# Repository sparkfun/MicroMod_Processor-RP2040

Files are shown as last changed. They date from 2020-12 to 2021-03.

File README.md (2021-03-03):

SparkFun MicroMod Processor RP2040
========================================

SparkFun MicroMod Processor RP2040 (https://www.sparkfun.com/products/17720)

[*SparkFun MicroMod Processor RP2040 (DEV-17720)*](https://www.sparkfun.com/products/17720)

The SparkFun MicroMod Pi RP2040 Processor Board is a low-cost, high-performance board with flexible digital interfaces featuring the Raspberry Pi Foundation's RP2040 microcontroller. With the MicroMod M.2 connector, connecting your MicroMod Pi RP2040 Processor Board is a breeze. Simply match up the key on your processor's beveled edge connector to the key on the M.2 connector and secure it with a screw (included with all Carrier Boards).

Repository Contents
-------------------

* **/Documentation** - Data sheets, additional product information
* **/Hardware** - Eagle design files (.brd, .sch)

Documentation
--------------

* **[Hookup Guide](https://learn.sparkfun.com/tutorials/1495)** - Basic hookup guide for the MicroMod Processor RP2040
* **[SparkFun Graphical Datasheets](https://github.com/sparkfun/Graphical_Datasheets)** - Graphical datasheets for various SparkFun products.

Product Versions
----------------

* [DEV-17720](https://www.sparkfun.com/products/17720) -  initial release

License Information
-------------------

This product is _**open source**_! 

Please review the LICENSE.md file for license information. 

If you have any questions or concerns on licensing, please contact technical support on our [SparkFun forums](https://forum.sparkfun.com/viewforum.php?f=152).

Distributed as-is; no warranty is given.

- Your friends at SparkFun.

_<COLLABORATION CREDIT>_

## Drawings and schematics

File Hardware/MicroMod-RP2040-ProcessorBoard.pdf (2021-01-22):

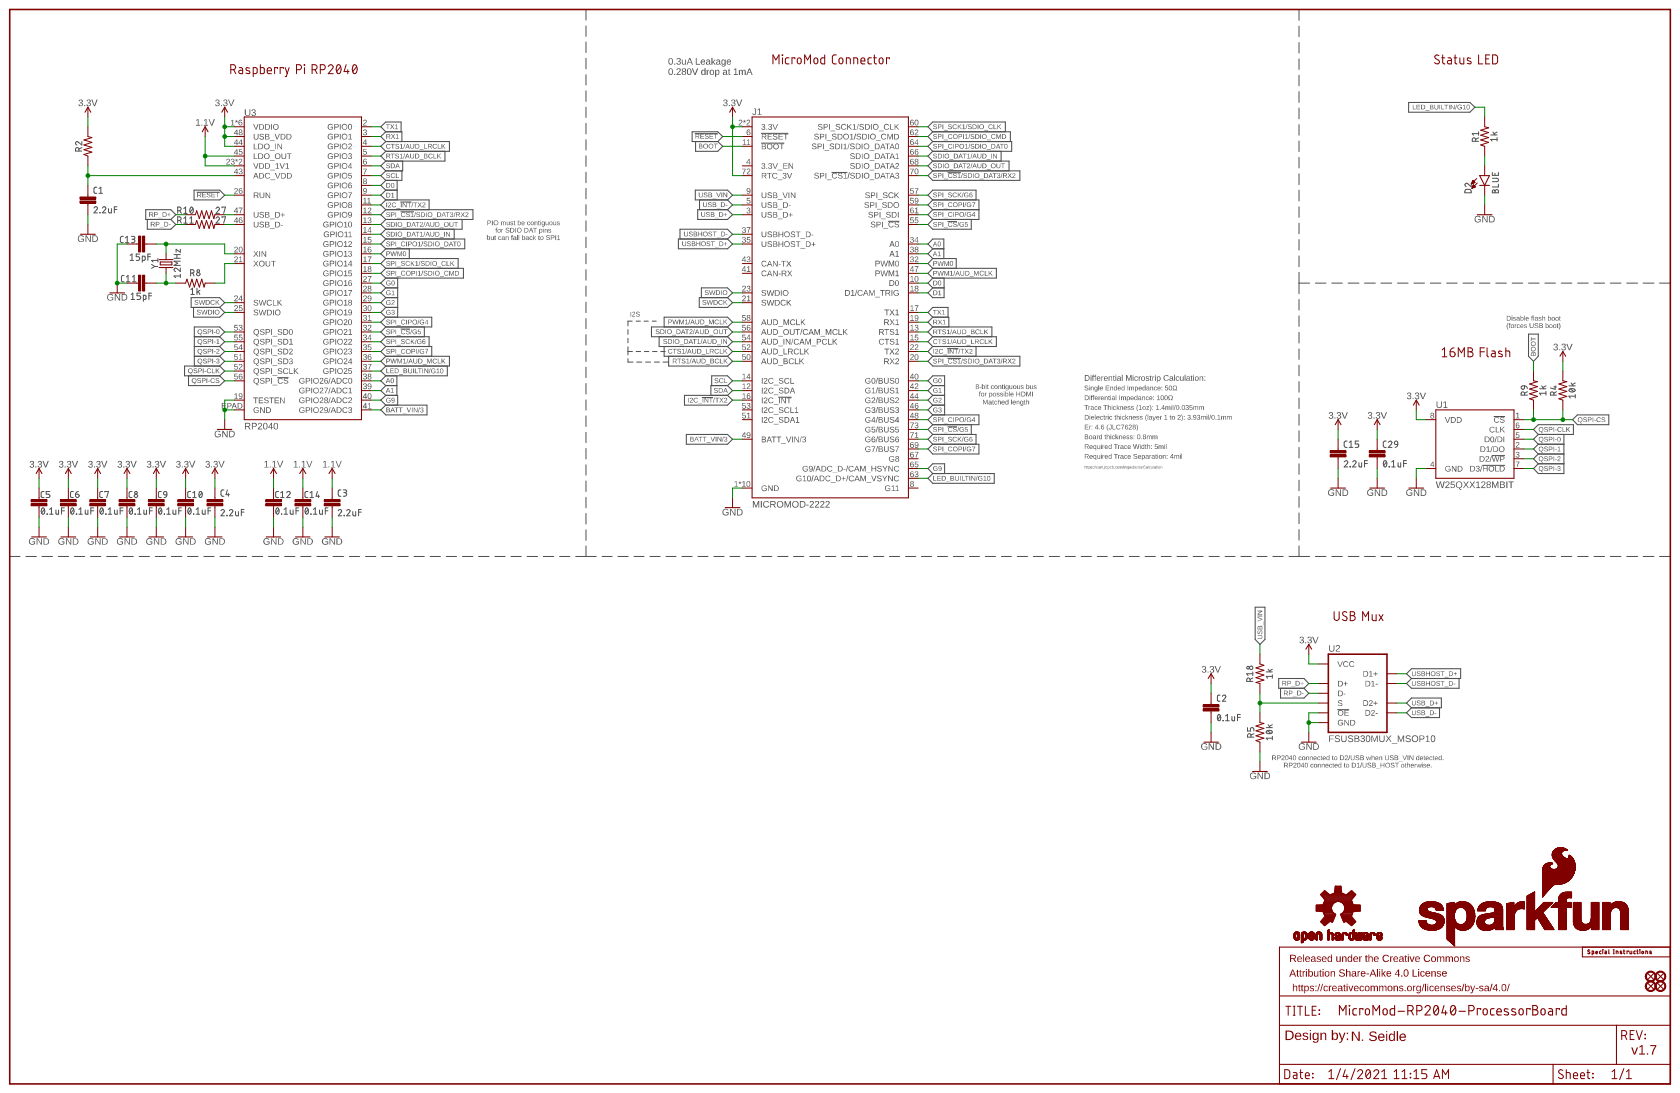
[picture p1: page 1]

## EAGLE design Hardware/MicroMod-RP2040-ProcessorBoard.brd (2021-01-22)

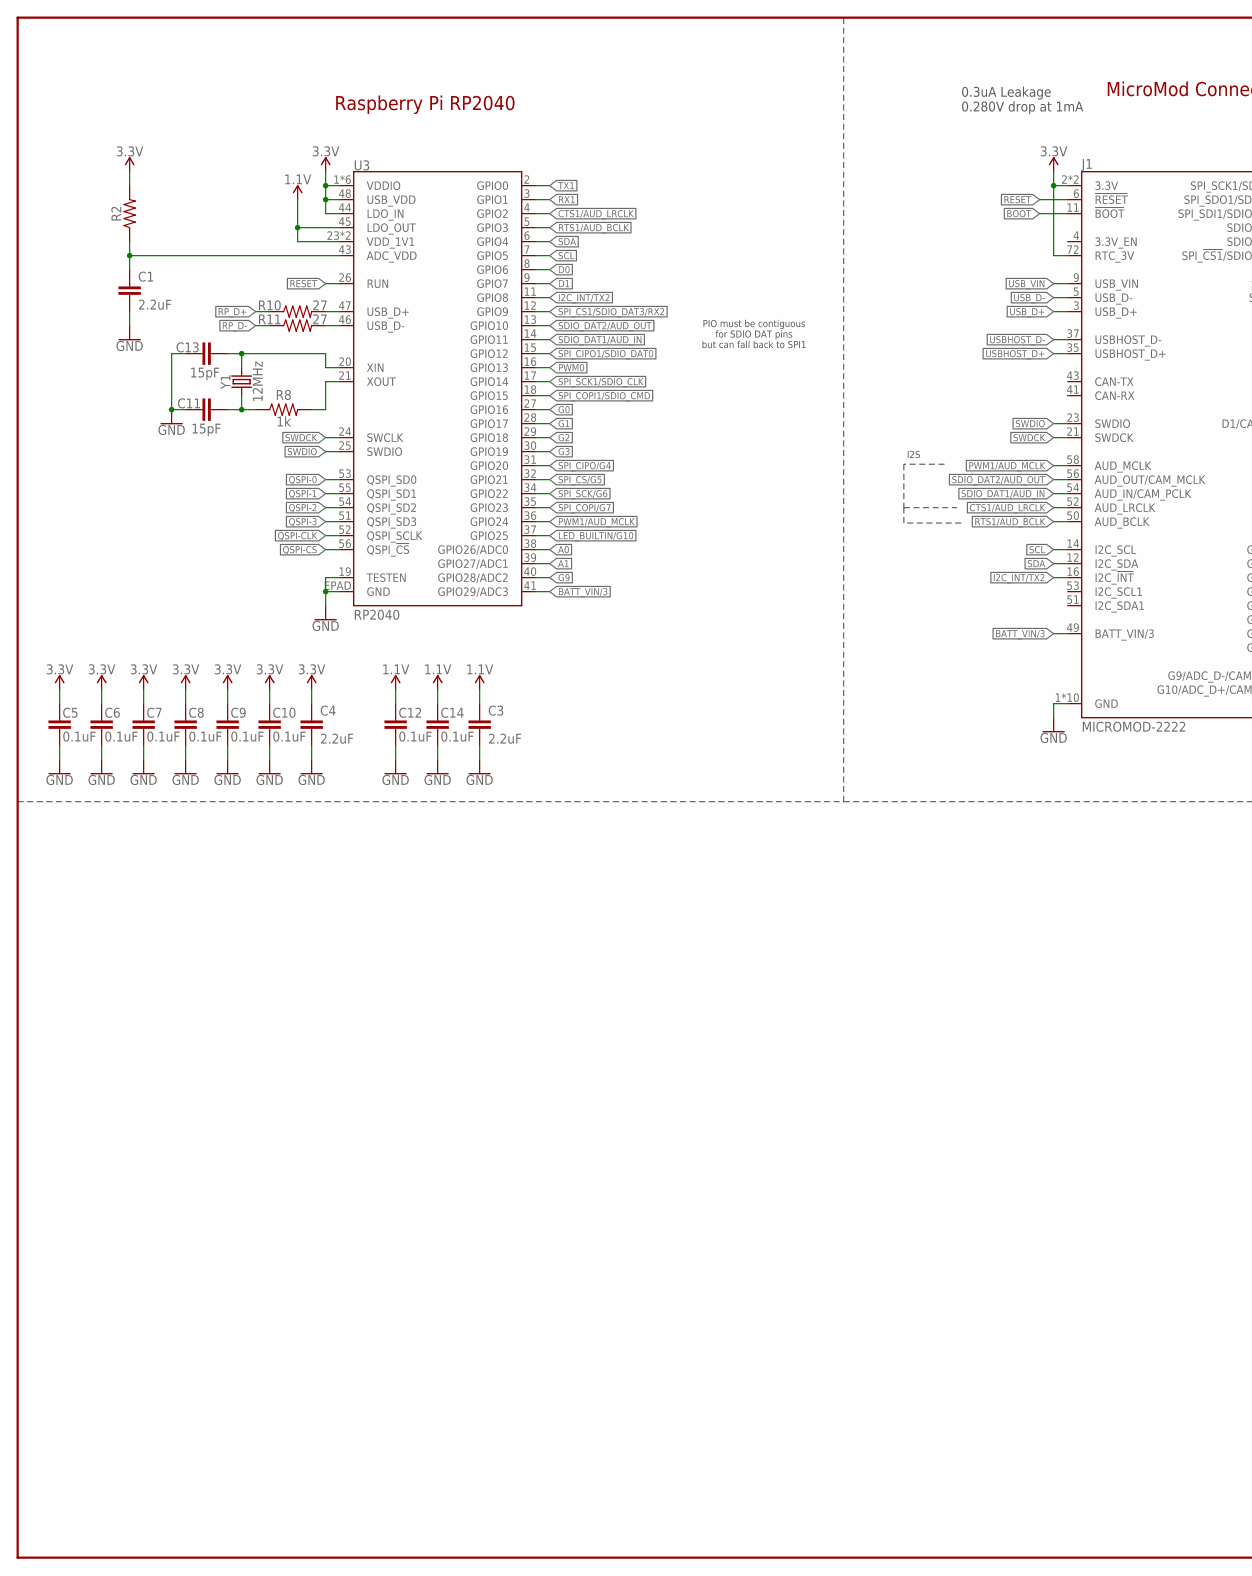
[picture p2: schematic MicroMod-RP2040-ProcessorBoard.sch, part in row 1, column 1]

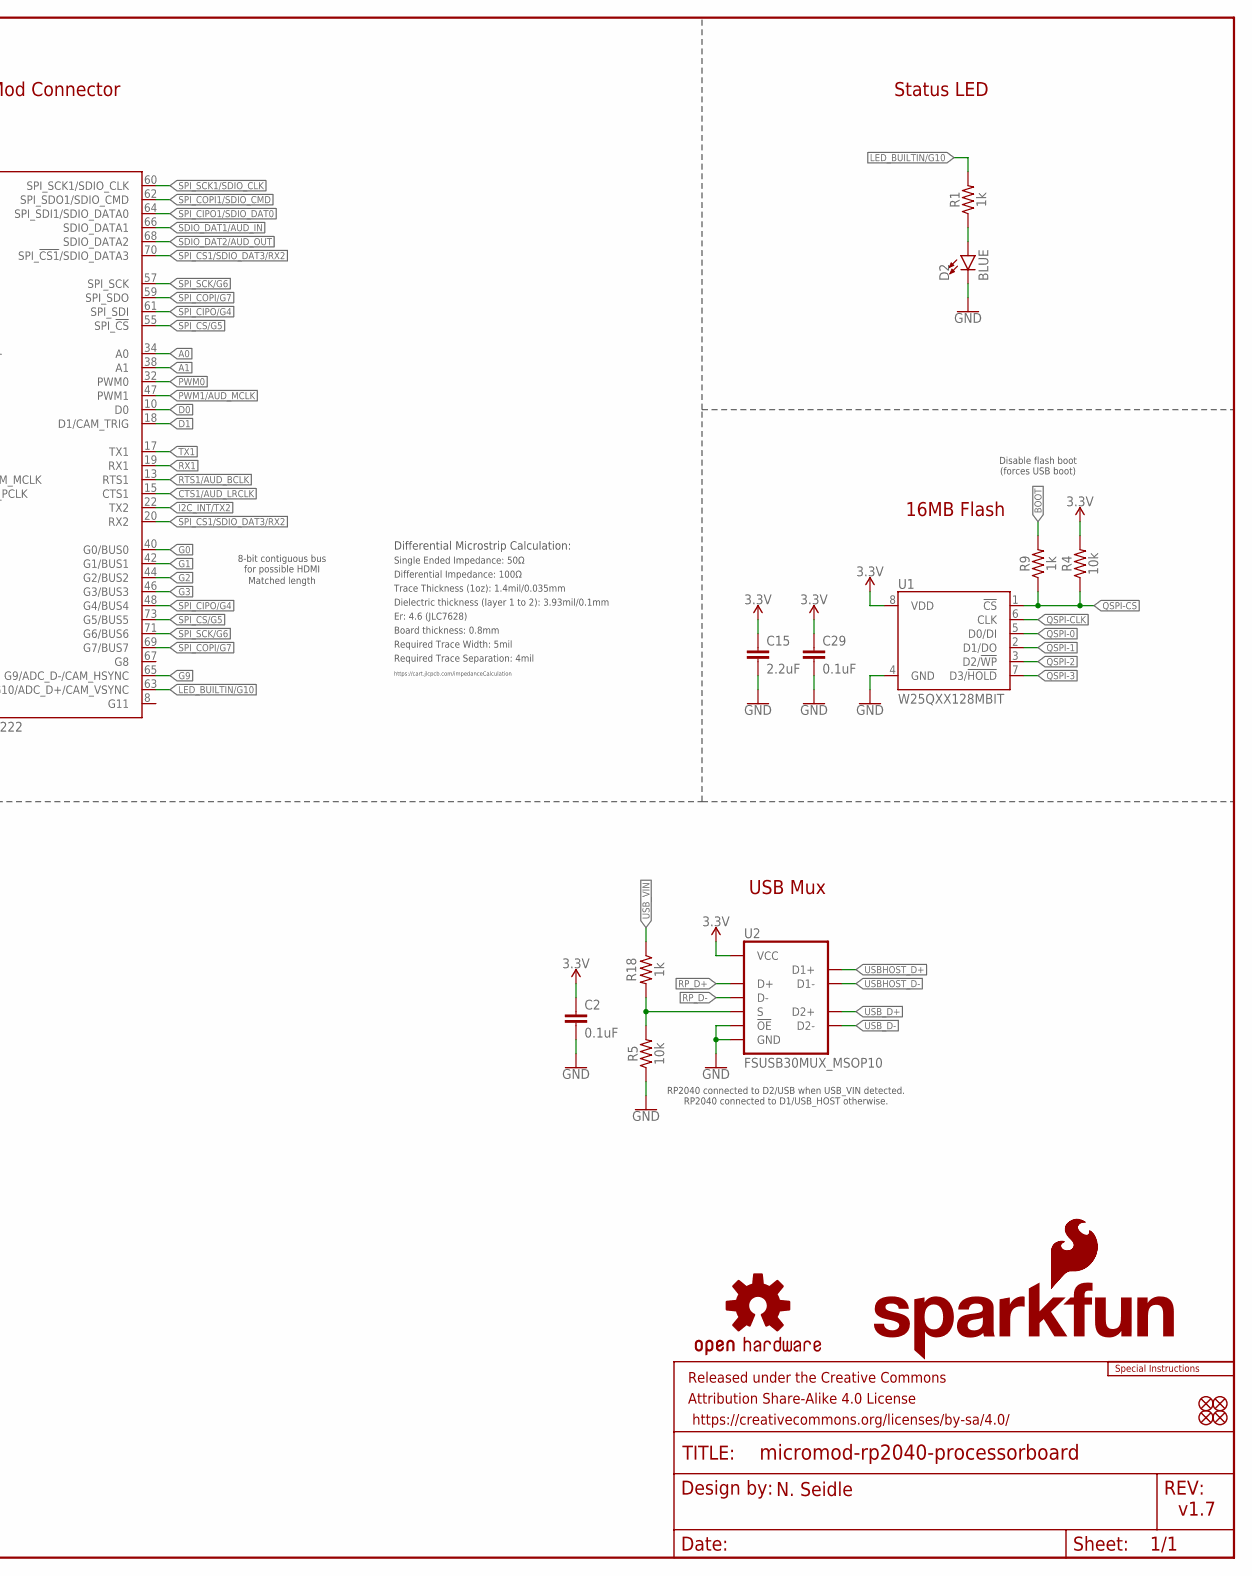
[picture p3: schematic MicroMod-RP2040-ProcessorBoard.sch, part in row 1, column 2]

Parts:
C1, C3, C4, C15: 2.2uF; 0402-TIGHT
C2, C5, C6, C7, C8, C9, C10, C12, C14, C29: 0.1uF; 0402-TIGHT
C11, C13: 15pF; 0402-TIGHT
D2: BLUE; LED-0603
FD1, FD2, FD3, FD4: FIDUCIALUFIDUCIAL; FIDUCIAL-MICRO
FRAME1: FRAME-LEDGER; CREATIVE_COMMONS
J1: MICROMOD-2222; M.2-CARD-E-22
LOGO1: SFE_LOGO_NAME_FLAME.1_INCH; SFE_LOGO_NAME_FLAME_.1
LOGO2: SFE_LOGO_FLAME.1_INCH; SFE_LOGO_FLAME_.1
LOGO3: OSHW-LOGOMINI; OSHW-LOGO-MINI
LOGO4: SPECIAL_INSTRUCTIONS-ORDERING; ORDERING_INSTRUCTIONS
R1, R8, R9, R18: 1k; 0402-TIGHT
R2: 200OHM-0402T-1/16W-1%; 0402-TIGHT
R4, R5: 10k; 0402-TIGHT
R10, R11: 27; 0402-TIGHT
U1: W25QXX128MBIT; WSON-8-6X5-SKINNY_CENTERPAD
U2: FSUSB30MUX_MSOP10; MSOP10
U3: RP2040; QFN-56
Y1: 12MHz; CRYSTAL-SMD-2X2.5MM

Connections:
1.1V: C3.1, C12.1, C14.1, U3.23 (VDD_1V1), U3.45 (LDO_OUT), U3.50 (VDD_1V1)
3.3V: C2.1, C4.1, C5.1, C6.1, C7.1, C8.1, C9.1, C10.1, C15.1, C29.1, J1.2 (3.3V), J1.72 (RTC_3V), J1.74 (3.3V), R2.2, R4.2, U1.8 (VDD), U2.10 (VCC), U3.1 (VDDIO), U3.10 (VDDIO), U3.22 (VDDIO), U3.33 (VDDIO), U3.42 (VDDIO), U3.44 (LDO_IN), U3.48 (USB_VDD), U3.49 (VDDIO)
!RESET!: J1.6 (!RESET!), U3.26 (RUN)
A0: J1.34 (A0), U3.38 (GPIO26/ADC0)
A1: J1.38 (A1), U3.39 (GPIO27/ADC1)
ADC_VDD: C1.1, R2.1, U3.43 (ADC_VDD)
BATT_VIN/3: J1.49 (BATT_VIN/3), U3.41 (GPIO29/ADC3)
BOOT: J1.11 (!BOOT!), R9.2
CTS1/AUD_LRCLK: J1.15 (CTS1), J1.52 (AUD_LRCLK), U3.4 (GPIO2)
D0: J1.10 (D0), U3.8 (GPIO6)
D1: J1.18 (D1/CAM_TRIG), U3.9 (GPIO7)
G0: J1.40 (G0/BUS0), U3.27 (GPIO16)
G1: J1.42 (G1/BUS1), U3.28 (GPIO17)
G2: J1.44 (G2/BUS2), U3.29 (GPIO18)
G3: J1.46 (G3/BUS3), U3.30 (GPIO19)
G9: J1.65 (G9/ADC_D-/CAM_HSYNC), U3.40 (GPIO28/ADC2)
GND: C1.2, C2.2, C3.2, C4.2, C5.2, C6.2, C7.2, C8.2, C9.2, C10.2, C11.1, C12.2, C13.1, C14.2, C15.2, C29.2, D2.C, J1.1 (GND), J1.7 (GND), J1.33 (GND), J1.36 (GND), J1.39 (GND), J1.45 (GND), J1.75 (GND), J1.GND1 (GND), J1.GND2 (GND), J1.GND3 (GND), R5.1, U1.4 (GND), U2.5 (GND), U2.9 (!OE!), U3.19 (TESTEN), U3.EPAD (GND)
I2C_!INT!/TX2: J1.16 (I2C_!INT!), J1.22 (TX2), U3.11 (GPIO8)
LED_BUILTIN/G10: J1.63 (G10/ADC_D+/CAM_VSYNC), R1.2, U3.37 (GPIO25)
unnamed: D2.A, R1.1
unnamed: R8.2, U3.21 (XOUT)
unnamed: C13.2, U3.20 (XIN), Y1.P3 (2)
unnamed: C11.2, R8.1, Y1.P1 (1)
PWM0: J1.32 (PWM0), U3.16 (GPIO13)
PWM1/AUD_MCLK: J1.47 (PWM1), J1.58 (AUD_MCLK), U3.36 (GPIO24)
QSPI-0: U1.5 (D0/DI), U3.53 (QSPI_SD0)
QSPI-1: U1.2 (D1/DO), U3.55 (QSPI_SD1)
QSPI-2: U1.3 (D2/!WP!), U3.54 (QSPI_SD2)
QSPI-3: U1.7 (D3/!HOLD!), U3.51 (QSPI_SD3)
QSPI-CLK: U1.6 (CLK), U3.52 (QSPI_SCLK)
QSPI-CS: R4.1, R9.1, U1.1 (!CS!), U3.56 (QSPI_!CS!)
RP_D1+: R10.2, U3.47 (USB_D+)
RP_D1-: R11.2, U3.46 (USB_D-)
RP_D+: R10.1, U2.4 (D+)
RP_D-: R11.1, U2.6 (D-)
RTS1/AUD_BCLK: J1.13 (RTS1), J1.50 (AUD_BCLK), U3.5 (GPIO3)
RX1: J1.19 (RX1), U3.3 (GPIO1)
SCL: J1.14 (I2C_SCL), U3.7 (GPIO5)
SDA: J1.12 (I2C_SDA), U3.6 (GPIO4)
SDIO_DAT1/AUD_IN: J1.54 (AUD_IN/CAM_PCLK), J1.66 (SDIO_DATA1), U3.14 (GPIO11)
SDIO_DAT2/AUD_OUT: J1.56 (AUD_OUT/CAM_MCLK), J1.68 (SDIO_DATA2), U3.13 (GPIO10)
SPI_!CS1!/SDIO_DAT3/RX2: J1.20 (RX2), J1.70 (SPI_!CS1!/SDIO_DATA3), U3.12 (GPIO9)
SPI_!CS!/G5: J1.55 (SPI_!CS!), J1.73 (G5/BUS5), U3.32 (GPIO21)
SPI_CIPO1/SDIO_DAT0: J1.64 (SPI_SDI1/SDIO_DATA0), U3.15 (GPIO12)
SPI_CIPO/G4: J1.48 (G4/BUS4), J1.61 (SPI_SDI), U3.31 (GPIO20)
SPI_COPI1/SDIO_CMD: J1.62 (SPI_SDO1/SDIO_CMD), U3.18 (GPIO15)
SPI_COPI/G7: J1.59 (SPI_SDO), J1.69 (G7/BUS7), U3.35 (GPIO23)
SPI_SCK1/SDIO_CLK: J1.60 (SPI_SCK1/SDIO_CLK), U3.17 (GPIO14)
SPI_SCK/G6: J1.57 (SPI_SCK), J1.71 (G6/BUS6), U3.34 (GPIO22)
SWDCK: J1.21 (SWDCK), U3.24 (SWCLK)
SWDIO: J1.23 (SWDIO), U3.25 (SWDIO)
TX1: J1.17 (TX1), U3.2 (GPIO0)
USBHOST_D+: J1.35 (USBHOST_D+), U2.2 (D1+)
USBHOST_D-: J1.37 (USBHOST_D-), U2.8 (D1-)
USB_D+: J1.3 (USB_D+), U2.3 (D2+)
USB_D-: J1.5 (USB_D-), U2.7 (D2-)
USB_MUX_SIG: R5.2, R18.2, U2.1 (S)
USB_VIN: J1.9 (USB_VIN), R18.1

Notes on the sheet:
MicroMod Connector
v1.7
N. Seidle
Raspberry Pi RP2040
Status LED
16MB Flash
Disable flash boot (forces USB boot)
PIO must be contiguous for SDIO DAT pins but can fall back to SPI1
8-bit contiguous bus for possible HDMI
0.3uA Leakage 0.280V drop at 1mA
I2S
USB Mux
RP2040 connected to D2/USB when USB_VIN detected. RP2040 connected to D1/USB_HOST otherwise.
Board thickness: 0.8mm
Er: 4.6 (JLC7628)
Trace Thickness (1oz): 1.4mil/0.035mm
Single Ended Impedance: 50Ω
Dielectric thickness (layer 1 to 2): 3.93mil/0.1mm
https://cart.jlcpcb.com/impedanceCalculation
Differential Microstrip Calculation:
Required Trace Separation: 4mil
Required Trace Width: 5mil
Differential Impedance: 100Ω
Matched length

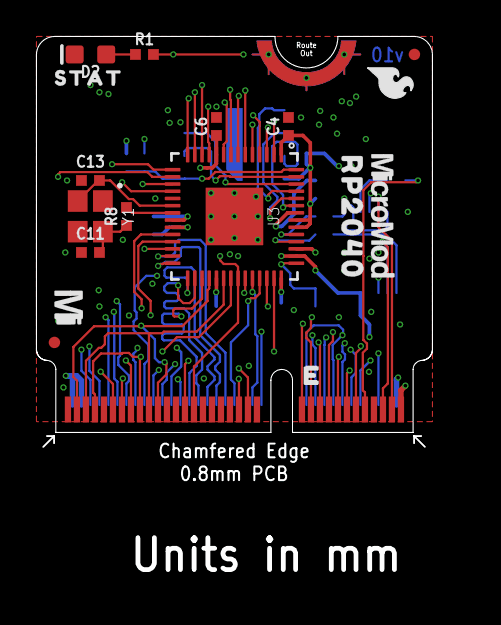
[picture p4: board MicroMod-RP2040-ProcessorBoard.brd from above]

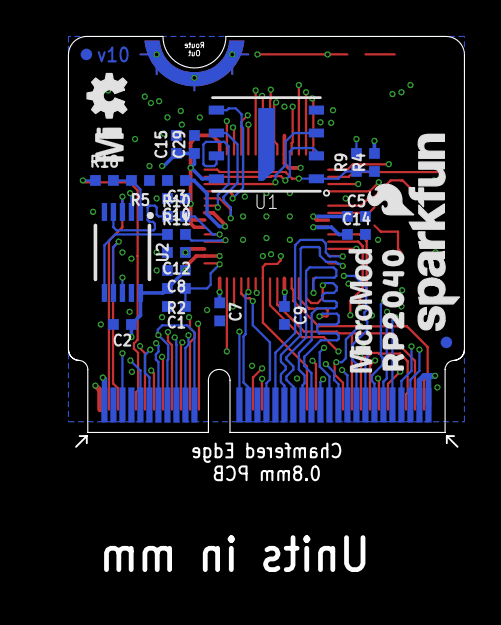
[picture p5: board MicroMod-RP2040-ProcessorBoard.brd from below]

Board: 4 copper layers, 22.0 x 22.8 mm, 47 parts (28 on the bottom side), 58 nets.

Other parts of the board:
U$1, U$7: MICROMOD_MI_LOGO_.35
U$3, U$12: MICROMOD_LOGO_.3
U$4, U$9: RP20400
U$11: STAT0

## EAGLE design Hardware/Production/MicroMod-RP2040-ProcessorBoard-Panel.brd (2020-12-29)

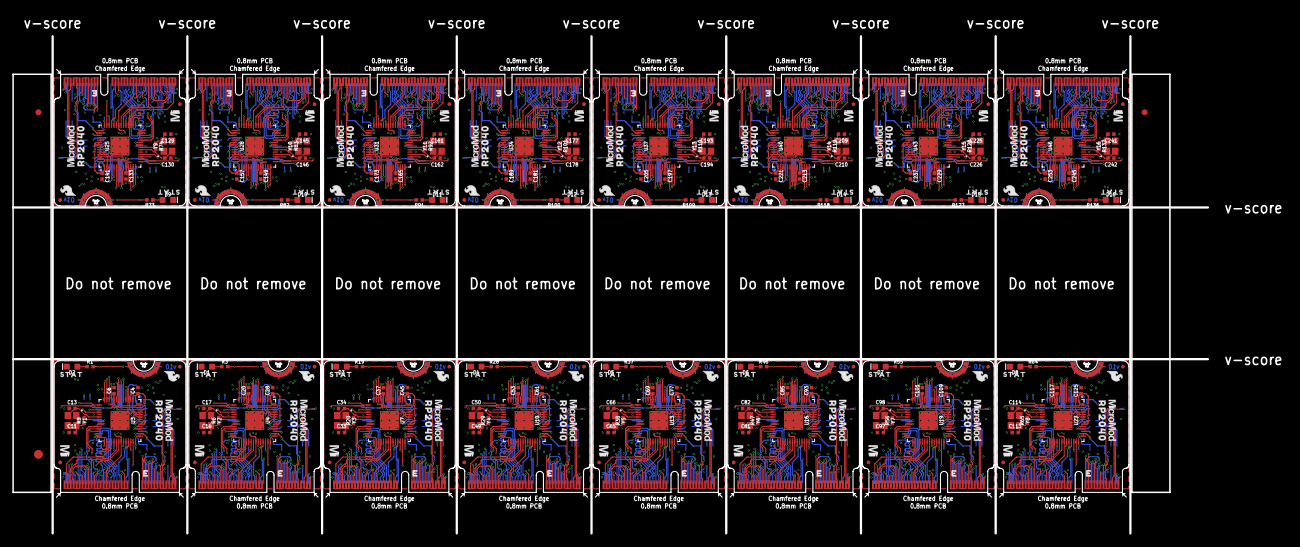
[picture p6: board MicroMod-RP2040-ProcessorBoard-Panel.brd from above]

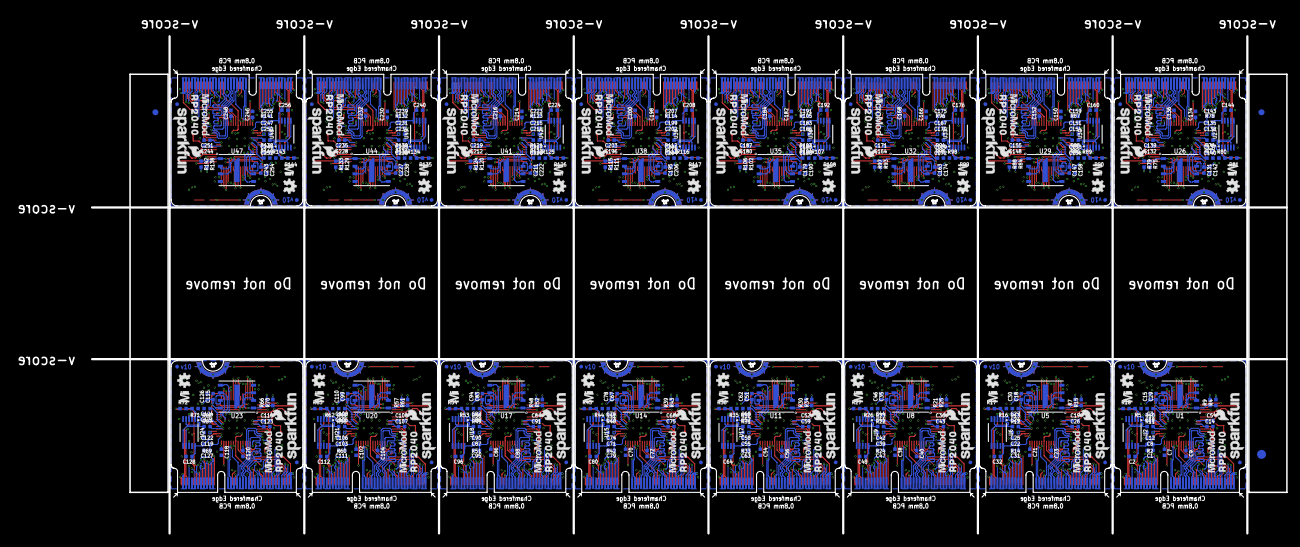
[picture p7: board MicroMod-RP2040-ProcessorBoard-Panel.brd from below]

Board: 4 copper layers, 199.6 x 83.1 mm, 726 parts (451 on the bottom side), 928 nets.

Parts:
C1, C3, C4, C15, C27, C28, C30, C31, C44, C45, C46, C47, C60, C61, C62, C63, C76, C77, C78, C79, C92, C93, C94, C95, C108, C109, C110, C111, C124, C125, C126, C127, C140, C141, C142, C143, C156, C157, C158, C159, C172, C173, C174, C175, C188, C189, C190, C191, C204, C205, C206, C207, C220, C221, C222, C223, C236, C237, C238, C239, C252, C253, C254, C255: 2.2uF; 0402-TIGHT
C2, C5, C6, C7, C8, C9, C10, C12, C14, C18, C19, C20, C21, C22, C23, C24, C25, C26, C29, C32, C35, C36, C37, C38, C39, C40, C41, C42, C43, C48, C51, C52, C53, C54, C55, C56, C57, C58, C59, C64, C67, C68, C69, C70, C71, C72, C73, C74, C75, C80, C83, C84, C85, C86, C87, C88, C89, C90, C91, C96, C99, C100, C101, C102, C103, C104, C105, C106, C107, C112, C115, C116, C117, C118, C119, C120, C121, C122, C123, C128, C131, C132, C133, C134, C135, C136, C137, C138, C139, C144, C147, C148, C149, C150, C151, C152, C153, C154, C155, C160, C163, C164, C165, C166, C167, C168, C169, C170, C171, C176, C179, C180, C181, C182, C183, C184, C185, C186, C187, C192, C195, C196, C197, C198, C199, C200, C201, C202, C203, C208, C211, C212, C213, C214, C215, C216, C217, C218, C219, C224, C227, C228, C229, C230, C231, C232, C233, C234, C235, C240, C243, C244, C245, C246, C247, C248, C249, C250, C251, C256: 0.1uF; 0402-TIGHT
C11, C13, C16, C17, C33, C34, C49, C50, C65, C66, C81, C82, C97, C98, C113, C114, C129, C130, C145, C146, C161, C162, C177, C178, C193, C194, C209, C210, C225, C226, C241, C242: 15pF; 0402-TIGHT
D1, D2, D3, D4, D5, D6, D7, D8, D9, D10, D11, D12, D13, D14, D15, D16: BLUE; LED-0603
E$1, E$2, E$3, E$4: FIDUCIAL-1X2
E$5, E$6: FIDUCIAL-1.5X3
FD1, FD2, FD3, FD4, FD5, FD6, FD7, FD8, FD9, FD10, FD11, FD12, FD13, FD14, FD15, FD16, FD17, FD18, FD19, FD20, FD21, FD22, FD23, FD24, FD25, FD26, FD27, FD28, FD29, FD30, FD31, FD32, FD33, FD34, FD35, FD36, FD37, FD38, FD39, FD40, FD41, FD42, FD43, FD44, FD45, FD46, FD47, FD48, FD49, FD50, FD51, FD52, FD53, FD54, FD55, FD56, FD57, FD58, FD59, FD60, FD61, FD62, FD63, FD64: FIDUCIALUFIDUCIAL; FIDUCIAL-MICRO
J1, J2, J3, J4, J5, J6, J7, J8, J9, J10, J11, J12, J13, J14, J15, J16: MICROMOD-2222; M.2-CARD-E-22
LOGO1, LOGO5, LOGO8, LOGO11, LOGO14, LOGO17, LOGO20, LOGO23, LOGO26, LOGO29, LOGO32, LOGO35, LOGO38, LOGO41, LOGO44, LOGO47: SFE_LOGO_NAME_FLAME.1_INCH; SFE_LOGO_NAME_FLAME_.1
LOGO2, LOGO6, LOGO9, LOGO12, LOGO15, LOGO18, LOGO21, LOGO24, LOGO27, LOGO30, LOGO33, LOGO36, LOGO39, LOGO42, LOGO45, LOGO48: SFE_LOGO_FLAME.1_INCH; SFE_LOGO_FLAME_.1
LOGO3, LOGO4, LOGO7, LOGO10, LOGO13, LOGO16, LOGO19, LOGO22, LOGO25, LOGO28, LOGO31, LOGO34, LOGO37, LOGO40, LOGO43, LOGO46: OSHW-LOGOMINI; OSHW-LOGO-MINI
R1, R3, R6, R7, R8, R9, R17, R18, R19, R20, R21, R27, R28, R29, R30, R36, R37, R38, R39, R45, R46, R47, R48, R54, R55, R56, R57, R63, R64, R65, R66, R72, R73, R74, R75, R81, R82, R83, R84, R90, R91, R92, R93, R99, R100, R101, R102, R108, R109, R110, R111, R117, R118, R119, R120, R126, R127, R128, R129, R135, R136, R137, R138, R144: 1k; 0402-TIGHT
R2, R14, R24, R33, R42, R51, R60, R69, R78, R87, R96, R105, R114, R123, R132, R141: 200OHM-0402T-1/16W-1%; 0402-TIGHT
R4, R5, R15, R16, R25, R26, R34, R35, R43, R44, R52, R53, R61, R62, R70, R71, R79, R80, R88, R89, R97, R98, R106, R107, R115, R116, R124, R125, R133, R134, R142, R143: 10k; 0402-TIGHT
R10, R11, R12, R13, R22, R23, R31, R32, R40, R41, R49, R50, R58, R59, R67, R68, R76, R77, R85, R86, R94, R95, R103, R104, R112, R113, R121, R122, R130, R131, R139, R140: 27; 0402-TIGHT
U1, U5, U8, U11, U14, U17, U20, U23, U26, U29, U32, U35, U38, U41, U44, U47: W25QXX128MBIT; WSON-8-6X5-SKINNY_CENTERPAD
U2, U6, U9, U12, U15, U18, U21, U24, U27, U30, U33, U36, U39, U42, U45, U48: FSUSB30MUX_MSOP10; MSOP10
U3, U4, U7, U10, U13, U16, U19, U22, U25, U28, U31, U34, U37, U40, U43, U46: RP2040; QFN-56
U$1, U$2, U$5, U$7, U$15, U$16, U$22, U$23, U$29, U$30, U$36, U$37, U$43, U$44, U$50, U$51, U$57, U$58, U$64, U$65, U$71, U$72, U$78, U$79, U$85, U$86, U$92, U$93, U$99, U$100, U$106, U$107: MICROMOD_MI_LOGO_.35
U$3, U$10, U$12, U$13, U$19, U$20, U$26, U$27, U$33, U$34, U$40, U$41, U$47, U$48, U$54, U$55, U$61, U$62, U$68, U$69, U$75, U$76, U$82, U$83, U$89, U$90, U$96, U$97, U$103, U$104, U$110, U$111: MICROMOD_LOGO_.3
U$4, U$8, U$9, U$14, U$18, U$21, U$25, U$28, U$32, U$35, U$39, U$42, U$46, U$49, U$53, U$56, U$60, U$63, U$67, U$70, U$74, U$77, U$81, U$84, U$88, U$91, U$95, U$98, U$102, U$105, U$109, U$112: RP20400
U$6, U$11, U$17, U$24, U$31, U$38, U$45, U$52, U$59, U$66, U$73, U$80, U$87, U$94, U$101, U$108: STAT0
Y1, Y2, Y3, Y4, Y5, Y6, Y7, Y8, Y9, Y10, Y11, Y12, Y13, Y14, Y15, Y16: 12MHz; CRYSTAL-SMD-2X2.5MM

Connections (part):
1.1V: C3.1, C12.1, C14.1, U3.23, U3.45, U3.50
1.1V1: C25.1, C26.1, C27.1, U4.23, U4.45, U4.50
1.1V2: C42.1, C43.1, C44.1, U7.23, U7.45, U7.50
1.1V3: C58.1, C59.1, C60.1, U10.23, U10.45, U10.50
1.1V4: C74.1, C75.1, C76.1, U13.23, U13.45, U13.50
1.1V5: C90.1, C91.1, C92.1, U16.23, U16.45, U16.50
1.1V6: C106.1, C107.1, C108.1, U19.23, U19.45, U19.50
1.1V7: C122.1, C123.1, C124.1, U22.23, U22.45, U22.50
1.1V8: C138.1, C139.1, C140.1, U25.23, U25.45, U25.50
1.1V9: C154.1, C155.1, C156.1, U28.23, U28.45, U28.50
1.1V10: C170.1, C171.1, C172.1, U31.23, U31.45, U31.50
1.1V11: C186.1, C187.1, C188.1, U34.23, U34.45, U34.50
1.1V12: C202.1, C203.1, C204.1, U37.23, U37.45, U37.50
1.1V13: C218.1, C219.1, C220.1, U40.23, U40.45, U40.50
1.1V14: C234.1, C235.1, C236.1, U43.23, U43.45, U43.50
1.1V15: C250.1, C251.1, C252.1, U46.23, U46.45, U46.50
3.3V: C2.1, C4.1, C5.1, C6.1, C7.1, C8.1, C9.1, C10.1, C15.1, C29.1, J1.2, J1.72, J1.74, R2.2, R4.2, U1.8, U2.10, U3.1, U3.10, U3.22, U3.33, U3.42, U3.44, U3.48, U3.49
3.3V1: C18.1, C19.1, C20.1, C21.1, C22.1, C23.1, C24.1, C28.1, C30.1, C32.1, J2.2, J2.72, J2.74, R14.2, R15.2, U4.1, U4.10, U4.22, U4.33, U4.42, U4.44, U4.48, U4.49, U5.8, U6.10
3.3V2: C35.1, C36.1, C37.1, C38.1, C39.1, C40.1, C41.1, C45.1, C46.1, C48.1, J3.2, J3.72, J3.74, R24.2, R25.2, U7.1, U7.10, U7.22, U7.33, U7.42, U7.44, U7.48, U7.49, U8.8, U9.10
3.3V3: C51.1, C52.1, C53.1, C54.1, C55.1, C56.1, C57.1, C61.1, C62.1, C64.1, J4.2, J4.72, J4.74, R33.2, R34.2, U10.1, U10.10, U10.22, U10.33, U10.42, U10.44, U10.48, U10.49, U11.8, U12.10
3.3V4: C67.1, C68.1, C69.1, C70.1, C71.1, C72.1, C73.1, C77.1, C78.1, C80.1, J5.2, J5.72, J5.74, R42.2, R43.2, U13.1, U13.10, U13.22, U13.33, U13.42, U13.44, U13.48, U13.49, U14.8, U15.10
3.3V5: C83.1, C84.1, C85.1, C86.1, C87.1, C88.1, C89.1, C93.1, C94.1, C96.1, J6.2, J6.72, J6.74, R51.2, R52.2, U16.1, U16.10, U16.22, U16.33, U16.42, U16.44, U16.48, U16.49, U17.8, U18.10
3.3V6: C99.1, C100.1, C101.1, C102.1, C103.1, C104.1, C105.1, C109.1, C110.1, C112.1, J7.2, J7.72, J7.74, R60.2, R61.2, U19.1, U19.10, U19.22, U19.33, U19.42, U19.44, U19.48, U19.49, U20.8, U21.10
3.3V7: C115.1, C116.1, C117.1, C118.1, C119.1, C120.1, C121.1, C125.1, C126.1, C128.1, J8.2, J8.72, J8.74, R69.2, R70.2, U22.1, U22.10, U22.22, U22.33, U22.42, U22.44, U22.48, U22.49, U23.8, U24.10
3.3V8: C131.1, C132.1, C133.1, C134.1, C135.1, C136.1, C137.1, C141.1, C142.1, C144.1, J9.2, J9.72, J9.74, R78.2, R79.2, U25.1, U25.10, U25.22, U25.33, U25.42, U25.44, U25.48, U25.49, U26.8, U27.10
3.3V9: C147.1, C148.1, C149.1, C150.1, C151.1, C152.1, C153.1, C157.1, C158.1, C160.1, J10.2, J10.72, J10.74, R87.2, R88.2, U28.1, U28.10, U28.22, U28.33, U28.42, U28.44, U28.48, U28.49, U29.8, U30.10
3.3V10: C163.1, C164.1, C165.1, C166.1, C167.1, C168.1, C169.1, C173.1, C174.1, C176.1, J11.2, J11.72, J11.74, R96.2, R97.2, U31.1, U31.10, U31.22, U31.33, U31.42, U31.44, U31.48, U31.49, U32.8, U33.10
3.3V11: C179.1, C180.1, C181.1, C182.1, C183.1, C184.1, C185.1, C189.1, C190.1, C192.1, J12.2, J12.72, J12.74, R105.2, R106.2, U34.1, U34.10, U34.22, U34.33, U34.42, U34.44, U34.48, U34.49, U35.8, U36.10
3.3V12: C195.1, C196.1, C197.1, C198.1, C199.1, C200.1, C201.1, C205.1, C206.1, C208.1, J13.2, J13.72, J13.74, R114.2, R115.2, U37.1, U37.10, U37.22, U37.33, U37.42, U37.44, U37.48, U37.49, U38.8, U39.10
3.3V13: C211.1, C212.1, C213.1, C214.1, C215.1, C216.1, C217.1, C221.1, C222.1, C224.1, J14.2, J14.72, J14.74, R123.2, R124.2, U40.1, U40.10, U40.22, U40.33, U40.42, U40.44, U40.48, U40.49, U41.8, U42.10
3.3V14: C227.1, C228.1, C229.1, C230.1, C231.1, C232.1, C233.1, C237.1, C238.1, C240.1, J15.2, J15.72, J15.74, R132.2, R133.2, U43.1, U43.10, U43.22, U43.33, U43.42, U43.44, U43.48, U43.49, U44.8, U45.10
3.3V15: C243.1, C244.1, C245.1, C246.1, C247.1, C248.1, C249.1, C253.1, C254.1, C256.1, J16.2, J16.72, J16.74, R141.2, R142.2, U46.1, U46.10, U46.22, U46.33, U46.42, U46.44, U46.48, U46.49, U47.8, U48.10
!RESET!: J1.6, U3.26
!RESET!1: J2.6, U4.26
!RESET!2: J3.6, U7.26
!RESET!3: J4.6, U10.26
!RESET!4: J5.6, U13.26
!RESET!5: J6.6, U16.26
!RESET!6: J7.6, U19.26
!RESET!7: J8.6, U22.26
!RESET!8: J9.6, U25.26
!RESET!9: J10.6, U28.26
!RESET!10: J11.6, U31.26
!RESET!11: J12.6, U34.26
!RESET!12: J13.6, U37.26
!RESET!13: J14.6, U40.26
!RESET!14: J15.6, U43.26
!RESET!15: J16.6, U46.26
ADC0: J1.34, U3.38
ADC1: J1.38, U3.39
ADC2: J2.34, U4.38
ADC3: J2.38, U4.39
ADC4: J3.34, U7.38
ADC5: J3.38, U7.39
ADC6: J4.34, U10.38
ADC7: J4.38, U10.39
ADC8: J5.34, U13.38
ADC9: J5.38, U13.39
ADC10: J6.34, U16.38
ADC11: J6.38, U16.39
ADC12: J7.34, U19.38
ADC13: J7.38, U19.39
ADC14: J8.34, U22.38
ADC15: J8.38, U22.39
ADC16: J9.34, U25.38
ADC17: J9.38, U25.39
ADC18: J10.34, U28.38
ADC19: J10.38, U28.39
ADC20: J11.34, U31.38
ADC21: J11.38, U31.39
ADC22: J12.34, U34.38
ADC23: J12.38, U34.39
ADC24: J13.34, U37.38
ADC25: J13.38, U37.39
ADC26: J14.34, U40.38
ADC27: J14.38, U40.39
ADC28: J15.34, U43.38
ADC29: J15.38, U43.39
ADC30: J16.34, U46.38
ADC31: J16.38, U46.39
ADC_VDD: C1.1, R2.1, U3.43
ADC_VDD1: C31.1, R14.1, U4.43
ADC_VDD2: C47.1, R24.1, U7.43
ADC_VDD3: C63.1, R33.1, U10.43
ADC_VDD4: C79.1, R42.1, U13.43
ADC_VDD5: C95.1, R51.1, U16.43
ADC_VDD6: C111.1, R60.1, U19.43
ADC_VDD7: C127.1, R69.1, U22.43
ADC_VDD8: C143.1, R78.1, U25.43
ADC_VDD9: C159.1, R87.1, U28.43
ADC_VDD10: C175.1, R96.1, U31.43
ADC_VDD11: C191.1, R105.1, U34.43
ADC_VDD12: C207.1, R114.1, U37.43
ADC_VDD13: C223.1, R123.1, U40.43
ADC_VDD14: C239.1, R132.1, U43.43
ADC_VDD15: C255.1, R141.1, U46.43
BATT_VIN/1: J2.49, U4.41
BATT_VIN/2: J3.49, U7.41
BATT_VIN/3: J1.49, U3.41
BATT_VIN/4: J4.49, U10.41
BATT_VIN/5: J5.49, U13.41
BATT_VIN/6: J6.49, U16.41
BATT_VIN/7: J7.49, U19.41
BATT_VIN/8: J8.49, U22.41
BATT_VIN/9: J9.49, U25.41
BATT_VIN/10: J10.49, U28.41
BATT_VIN/11: J11.49, U31.41
BATT_VIN/12: J12.49, U34.41
BATT_VIN/13: J13.49, U37.41
BATT_VIN/14: J14.49, U40.41
BATT_VIN/15: J15.49, U43.41
BATT_VIN/16: J16.49, U46.41
BOOT: J1.11, R9.2
BOOT1: J2.11, R7.2
BOOT2: J3.11, R21.2
BOOT3: J4.11, R30.2
BOOT4: J5.11, R39.2
BOOT5: J6.11, R48.2
BOOT6: J7.11, R57.2
BOOT7: J8.11, R66.2
BOOT8: J9.11, R75.2
BOOT9: J10.11, R84.2
BOOT10: J11.11, R93.2
BOOT11: J12.11, R102.2
BOOT12: J13.11, R111.2
BOOT13: J14.11, R120.2
BOOT14: J15.11, R129.2
BOOT15: J16.11, R138.2
CTS1/AUD_LRCLK: J1.15, J1.52, U3.4
CTS1/AUD_LRCLK1: J2.15, J2.52, U4.4
CTS1/AUD_LRCLK2: J3.15, J3.52, U7.4
CTS1/AUD_LRCLK3: J4.15, J4.52, U10.4
CTS1/AUD_LRCLK4: J5.15, J5.52, U13.4
CTS1/AUD_LRCLK5: J6.15, J6.52, U16.4
CTS1/AUD_LRCLK6: J7.15, J7.52, U19.4
CTS1/AUD_LRCLK7: J8.15, J8.52, U22.4
CTS1/AUD_LRCLK8: J9.15, J9.52, U25.4
CTS1/AUD_LRCLK9: J10.15, J10.52, U28.4
CTS1/AUD_LRCLK10: J11.15, J11.52, U31.4
CTS1/AUD_LRCLK11: J12.15, J12.52, U34.4
CTS1/AUD_LRCLK12: J13.15, J13.52, U37.4
CTS1/AUD_LRCLK13: J14.15, J14.52, U40.4
CTS1/AUD_LRCLK14: J15.15, J15.52, U43.4
CTS1/AUD_LRCLK15: J16.15, J16.52, U46.4
D0: J1.10, U3.8
D1: J1.18, U3.9
D2: J2.10, U4.8
D3: J2.18, U4.9
D4: J3.10, U7.8
D5: J3.18, U7.9
D6: J4.10, U10.8
D7: J4.18, U10.9
D8: J5.10, U13.8
D9: J5.18, U13.9
D10: J6.10, U16.8
D11: J6.18, U16.9
D12: J7.10, U19.8
D13: J7.18, U19.9
D14: J8.10, U22.8
D15: J8.18, U22.9
D16: J9.10, U25.8
D17: J9.18, U25.9
D18: J10.10, U28.8
D19: J10.18, U28.9
D20: J11.10, U31.8
D21: J11.18, U31.9
D22: J12.10, U34.8
D23: J12.18, U34.9
D24: J13.10, U37.8
D25: J13.18, U37.9
D26: J14.10, U40.8
D27: J14.18, U40.9
D28: J15.10, U43.8
D29: J15.18, U43.9
D30: J16.10, U46.8
D31: J16.18, U46.9
GND: C1.2, C2.2, C3.2, C4.2, C5.2, C6.2, C7.2, C8.2, C9.2, C10.2, C11.1, C12.2, C13.1, C14.2, C15.2, C29.2, D2.C, J1.1, J1.7, J1.33, J1.36, J1.39, J1.45, J1.75, J1.GND1, J1.GND2, J1.GND3, R5.1, U1.4, U2.5, U2.9, U3.19, U3.EPAD
GND1: C16.1, C17.1, C18.2, C19.2, C20.2, C21.2, C22.2, C23.2, C24.2, C25.2, C26.2, C27.2, C28.2, C30.2, C31.2, C32.2, D1.C, J2.1, J2.7, J2.33, J2.36, J2.39, J2.45, J2.75, J2.GND1, J2.GND2, J2.GND3, R16.1, U4.19, U4.EPAD, U5.4, U6.5, U6.9
GND2: C33.1, C34.1, C35.2, C36.2, C37.2, C38.2, C39.2, C40.2, C41.2, C42.2, C43.2, C44.2, C45.2, C46.2, C47.2, C48.2, D3.C, J3.1, J3.7, J3.33, J3.36, J3.39, J3.45, J3.75, J3.GND1, J3.GND2, J3.GND3, R26.1, U7.19, U7.EPAD, U8.4, U9.5, U9.9
GND3: C49.1, C50.1, C51.2, C52.2, C53.2, C54.2, C55.2, C56.2, C57.2, C58.2, C59.2, C60.2, C61.2, C62.2, C63.2, C64.2, D4.C, J4.1, J4.7, J4.33, J4.36, J4.39, J4.45, J4.75, J4.GND1, J4.GND2, J4.GND3, R35.1, U10.19, U10.EPAD, U11.4, U12.5, U12.9
GND4: C65.1, C66.1, C67.2, C68.2, C69.2, C70.2, C71.2, C72.2, C73.2, C74.2, C75.2, C76.2, C77.2, C78.2, C79.2, C80.2, D5.C, J5.1, J5.7, J5.33, J5.36, J5.39, J5.45, J5.75, J5.GND1, J5.GND2, J5.GND3, R44.1, U13.19, U13.EPAD, U14.4, U15.5, U15.9
GND5: C81.1, C82.1, C83.2, C84.2, C85.2, C86.2, C87.2, C88.2, C89.2, C90.2, C91.2, C92.2, C93.2, C94.2, C95.2, C96.2, D6.C, J6.1, J6.7, J6.33, J6.36, J6.39, J6.45, J6.75, J6.GND1, J6.GND2, J6.GND3, R53.1, U16.19, U16.EPAD, U17.4, U18.5, U18.9
GND6: C97.1, C98.1, C99.2, C100.2, C101.2, C102.2, C103.2, C104.2, C105.2, C106.2, C107.2, C108.2, C109.2, C110.2, C111.2, C112.2, D7.C, J7.1, J7.7, J7.33, J7.36, J7.39, J7.45, J7.75, J7.GND1, J7.GND2, J7.GND3, R62.1, U19.19, U19.EPAD, U20.4, U21.5, U21.9
GND7: C113.1, C114.1, C115.2, C116.2, C117.2, C118.2, C119.2, C120.2, C121.2, C122.2, C123.2, C124.2, C125.2, C126.2, C127.2, C128.2, D8.C, J8.1, J8.7, J8.33, J8.36, J8.39, J8.45, J8.75, J8.GND1, J8.GND2, J8.GND3, R71.1, U22.19, U22.EPAD, U23.4, U24.5, U24.9
GND8: C129.1, C130.1, C131.2, C132.2, C133.2, C134.2, C135.2, C136.2, C137.2, C138.2, C139.2, C140.2, C141.2, C142.2, C143.2, C144.2, D9.C, J9.1, J9.7, J9.33, J9.36, J9.39, J9.45, J9.75, J9.GND1, J9.GND2, J9.GND3, R80.1, U25.19, U25.EPAD, U26.4, U27.5, U27.9
GND9: C145.1, C146.1, C147.2, C148.2, C149.2, C150.2, C151.2, C152.2, C153.2, C154.2, C155.2, C156.2, C157.2, C158.2, C159.2, C160.2, D10.C, J10.1, J10.7, J10.33, J10.36, J10.39, J10.45, J10.75, J10.GND1, J10.GND2, J10.GND3, R89.1, U28.19, U28.EPAD, U29.4, U30.5, U30.9
GND10: C161.1, C162.1, C163.2, C164.2, C165.2, C166.2, C167.2, C168.2, C169.2, C170.2, C171.2, C172.2, C173.2, C174.2, C175.2, C176.2, D11.C, J11.1, J11.7, J11.33, J11.36, J11.39, J11.45, J11.75, J11.GND1, J11.GND2, J11.GND3, R98.1, U31.19, U31.EPAD, U32.4, U33.5, U33.9
GND11: C177.1, C178.1, C179.2, C180.2, C181.2, C182.2, C183.2, C184.2, C185.2, C186.2, C187.2, C188.2, C189.2, C190.2, C191.2, C192.2, D12.C, J12.1, J12.7, J12.33, J12.36, J12.39, J12.45, J12.75, J12.GND1, J12.GND2, J12.GND3, R107.1, U34.19, U34.EPAD, U35.4, U36.5, U36.9
GND12: C193.1, C194.1, C195.2, C196.2, C197.2, C198.2, C199.2, C200.2, C201.2, C202.2, C203.2, C204.2, C205.2, C206.2, C207.2, C208.2, D13.C, J13.1, J13.7, J13.33, J13.36, J13.39, J13.45, J13.75, J13.GND1, J13.GND2, J13.GND3, R116.1, U37.19, U37.EPAD, U38.4, U39.5, U39.9
GND13: C209.1, C210.1, C211.2, C212.2, C213.2, C214.2, C215.2, C216.2, C217.2, C218.2, C219.2, C220.2, C221.2, C222.2, C223.2, C224.2, D14.C, J14.1, J14.7, J14.33, J14.36, J14.39, J14.45, J14.75, J14.GND1, J14.GND2, J14.GND3, R125.1, U40.19, U40.EPAD, U41.4, U42.5, U42.9
GND14: C225.1, C226.1, C227.2, C228.2, C229.2, C230.2, C231.2, C232.2, C233.2, C234.2, C235.2, C236.2, C237.2, C238.2, C239.2, C240.2, D15.C, J15.1, J15.7, J15.33, J15.36, J15.39, J15.45, J15.75, J15.GND1, J15.GND2, J15.GND3, R134.1, U43.19, U43.EPAD, U44.4, U45.5, U45.9
GND15: C241.1, C242.1, C243.2, C244.2, C245.2, C246.2, C247.2, C248.2, C249.2, C250.2, C251.2, C252.2, C253.2, C254.2, C255.2, C256.2, D16.C, J16.1, J16.7, J16.33, J16.36, J16.39, J16.45, J16.75, J16.GND1, J16.GND2, J16.GND3, R143.1, U46.19, U46.EPAD, U47.4, U48.5, U48.9
GPIO0: J1.40, U3.27
GPIO1: J1.42, U3.28
GPIO2: J1.44, U3.29
GPIO3: J1.46, U3.30
GPIO4: J2.42, U4.28
GPIO5: J2.46, U4.30
GPIO6: J2.44, U4.29
GPIO7: J2.40, U4.27
GPIO8: J2.65, U4.40
GPIO9: J1.65, U3.40
GPIO10: J3.42, U7.28
GPIO11: J3.46, U7.30
GPIO12: J3.44, U7.29
GPIO13: J3.40, U7.27
GPIO14: J3.65, U7.40
GPIO15: J4.42, U10.28
GPIO16: J4.46, U10.30
GPIO17: J4.44, U10.29
GPIO18: J4.40, U10.27
GPIO19: J4.65, U10.40
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

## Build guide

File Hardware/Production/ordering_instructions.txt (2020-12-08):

panel size, 194x70mm
PCB thickness, 0.8mm
number of layers, 4
soldermask color, Red
silkscreen color, White
oz copper, 1oz
finish, HASL lead free
stencils, top+bottom
pcs per panel, 16
min trace width, 0.1270mm / 0.0050in
min drill size, 0.2000mm / 0.0079in
filename to layer stackup 1/2/3/4: GTL, GL2, GL3, GBL

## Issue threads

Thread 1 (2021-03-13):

Why is RTC_3V connected to 3.3V?

cdwilson, 2021-03-13:
The RP2040 MicroMod shorts RTC_3V directly to 3.3V. What's the reason why these are shorted together on this processor board?

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

When 3.3V_EN is disabled on a carrier board, won't this cause the RTC battery to attempt to backfeed any devices on 3.3V rail (including devices on the carrier board 3.3V)?

The MicroMod specs for RTC_3V say:
> 3V provided by external coin cell or mini battery. Max draw=100μA. Connect to pins maintaining an RTC during power loss. Can be left NC.

The 3V3_LED on the carrier board by itself will exceed 100μA at 3V. Doesn't this violate the above spec for RTC_3V?

nseidle, 2021-03-15:
Yep, it's a mistake. I carried it over from Artemis (including the blocking diode). Then, after discussions with RPi it became obvious the RP2040 really doesn't have low power modes. I removed the diode but failed to remove the 3.3V RTC connection. While this connection will put a load on an external RTC battery I don't foresee any long term issues. You would see the same behavior with an unplugged Artemis or other micro that is left in full power mode.

I'll leave this open incase we rev the board in the future.

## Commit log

2020-11-13 Add ignore. Update prod_id on xtal. Remove backup files.
    [MicroMod-RP2040-ProcessorBoard.brd, MicroMod-RP2040-ProcessorBoard.sch]
2020-11-16 Add pullup to flash
    [MicroMod-RP2040-ProcessorBoard.brd, MicroMod-RP2040-ProcessorBoard.sch]
2020-12-08 Adding production files
    [MicroMod-RP2040-ProcessorBoard-Panel.GBL, MicroMod-RP2040-ProcessorBoard-Panel.GBO, MicroMod-RP2040-ProcessorBoard-Panel.GBP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]
2020-12-08 Update USB mux prod ID
    [MicroMod-RP2040-ProcessorBoard-Panel.brd, MicroMod-RP2040-ProcessorBoard.brd, MicroMod-RP2040-ProcessorBoard.sch]
2020-12-29 Update silk
    [MicroMod-RP2040-ProcessorBoard-Panel.brd, MicroMod-RP2040-ProcessorBoard.brd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]
2020-12-31 Rename nets to match MicroMod nomenclature
    [MicroMod-RP2040-ProcessorBoard.brd, MicroMod-RP2040-ProcessorBoard.sch]
2021-01-22 Update Schematic (PDF) and Add Dimensions in BRD File
    - regenerate schematic with updated nets based on MicroMod nomenclature
    - Add board measurements in dimensions layer
    [MicroMod-RP2040-ProcessorBoard.brd]
2021-03-23 Remove Outdated Files
    Removing outdated datasheet, the latest can be found from Raspberry Pi =)

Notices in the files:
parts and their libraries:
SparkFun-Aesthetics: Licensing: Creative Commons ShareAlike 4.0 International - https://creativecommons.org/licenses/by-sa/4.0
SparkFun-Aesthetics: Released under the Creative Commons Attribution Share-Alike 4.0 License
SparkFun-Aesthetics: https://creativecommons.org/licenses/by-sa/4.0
